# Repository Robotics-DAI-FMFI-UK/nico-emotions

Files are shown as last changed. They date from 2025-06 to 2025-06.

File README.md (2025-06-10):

# NICO: Humanoidná hlava s emóciami

Tento projekt predstavuje hlavu humanoidného robota **NICO**, ktorá dokáže zobrazovať rôzne emócie na tvári. Cieľom je vytvoriť platformu pre výskum v oblasti robotiky, umelej inteligencie a interakcie človek–robot.

## Hlavné vlastnosti

- Mechanická hlava s pohyblivými časťami tváre
- Sledovanie bodu v priestore pomocou očí
- Zobrazovanie základných emócií (radosť, smútok, strach, hnev, prekvapenie, zenchutenie,)
- Ovládanie pomocou jazykov *Python* a *C++*

## Delenie repozitára
1. 3D objects *(všetky vytlačiteľné súčasti robota vo formáte .STL)*
2. Microcontroller *(kódy riadiacej jednotky Raspberry Pi Pico 2)*
3. Python scripts *(vytvorené ovládače, ich využitie a generátor emócií)*

---

Radi privítame vaše nápady, opravy a vylepšenia.

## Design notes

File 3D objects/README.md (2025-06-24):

# Vymodelované objekty

Tento priečinok obsahuje nami vymodelované objekty novej humanoidnej hlavy a ich mechanizmov a zároveň upravený mechanizmus očí od autora [Rolf Jethon](https://bechele.de/?page_id=70).

V priečinkoch sa nachádza:
- Head - vymodelovaná hlava vo verzii .stl a zároveň aj ako objekt pre Fusion 360 sculpting ako štvorcová sieť
- Holder - držiak súčiastok, kamery a vonkajšej masky hlavy
- Eyes - použité súčiastky mechanizmu očí už s premodelovanými časťami

Ako zdroj sme použili modely pôvodnej hlavy od [SeedRobotics](https://github.com/seedrobotics/NICO-cad/tree/master).

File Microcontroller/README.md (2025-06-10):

# Program riadiacej jednotky

Tento kód bol navrhnutý pre použitie mikrokontroléra Raspberry Pi Pico 2. Program sme vyvíjali v prostedí Arduino IDE s rozšírením board manager [Arduino-Pico](https://github.com/earlephilhower/arduino-pico/). 

## Inštalácia rozšírenia
1. Treba otvoriť File -> Preferences
2. Do "Additional boards manager URLs" treba pridať:
https://github.com/earlephilhower/arduino-pico/releases/download/global/package_rp2040_index.json
3. V paneli "Boards manager" stačí vyhľadať "Raspberry Pi Pico"
4. Install

Pri inštalácií na windows je potrebné si dať pozor na pomenovanie účtu, pretože rozšírenie nedokáže korektne rozlišovať diakritiku v mene.

## Vlastné definovanie emócií

Predom sme definovali iba základné emócie. Ak má užívateľ vlastné preferencie, je potrebné zájsť do súboru **Emotions.cpp** a **Emotions.h**. Pri definovní novej emócie sú potrebné nasledovné kroky:

1. V **Emotions.cpp** vytvoríme nové pole pomenované podľa emócie a definujeme jednotlivé kroky emócie - {načasovanie, natočenia motorčekov}
2. V tom istom súbore pridáme do funkcie void Emotions::initialize() nové definície emócie:
- emotionMap[emotionCount].name = "NOVÁ EMÓCIA";
- emotionMap[emotionCount].data = nova_emocia;
- emotionMap[emotionCount++].steps = nova_emocia_steps;
3. Do súboru **Emotions.h** zapíšeme novú premennú - *extern int nova_emocia[][nova_emocia_steps]*;
4. Zvýšime počítadlo o +1 - *#define EMOTIONS_COUNT i+1*
5. Upravený kód nahráme do mikrokontroléra

Tento postup je zdĺhavý, preto ak nastane ďalšie rozširovanie práce, pridávanie vlastných emócií sa zlepší.

## Potrebné knižnice
- Arduino
- OneWire
- DallasTemperature

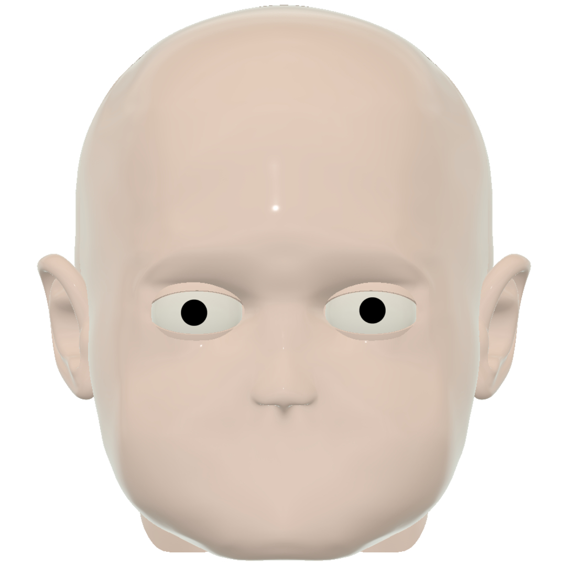
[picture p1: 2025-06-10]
Python scripts/position_generator/faces/normal.jpg

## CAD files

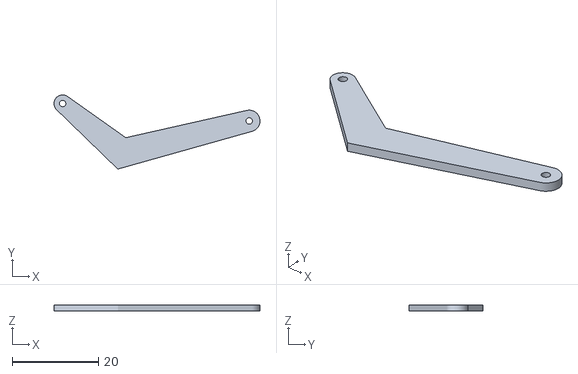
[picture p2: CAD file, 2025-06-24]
3D objects/Eyes/servo-eyeball-hinge-lever.stl
47.7 x 17.2 x 1.50

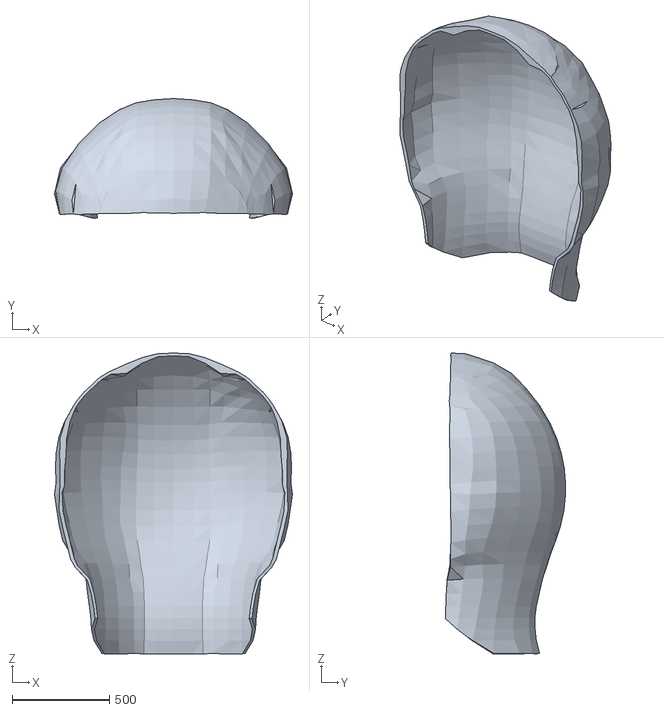
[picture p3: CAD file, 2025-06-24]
3D objects/Head/back.obj
1222.0 x 615.7 x 1545.3

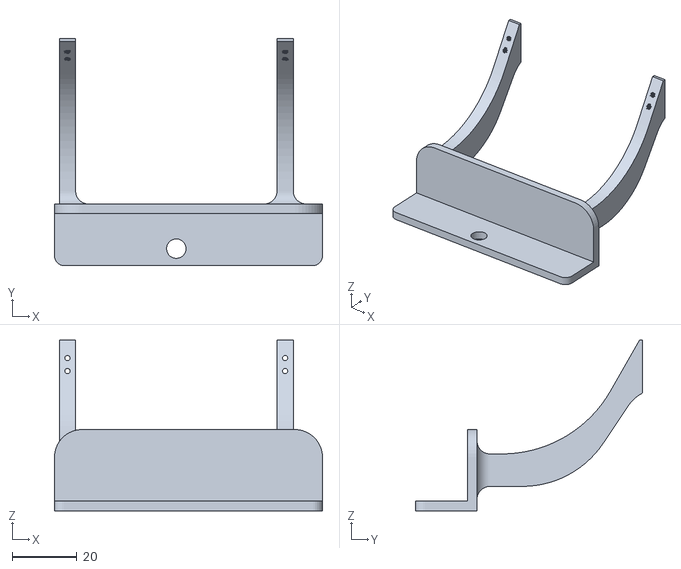
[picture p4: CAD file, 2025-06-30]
3D objects/Holder/camera_holder.stl
82.5 x 70.0 x 52.5

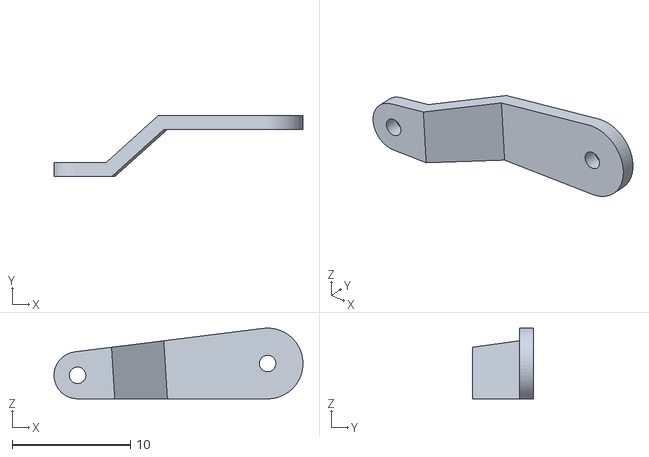
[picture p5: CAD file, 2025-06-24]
3D objects/Eyes/slider-servo-lever.stl
21.1 x 5.20 x 6.00

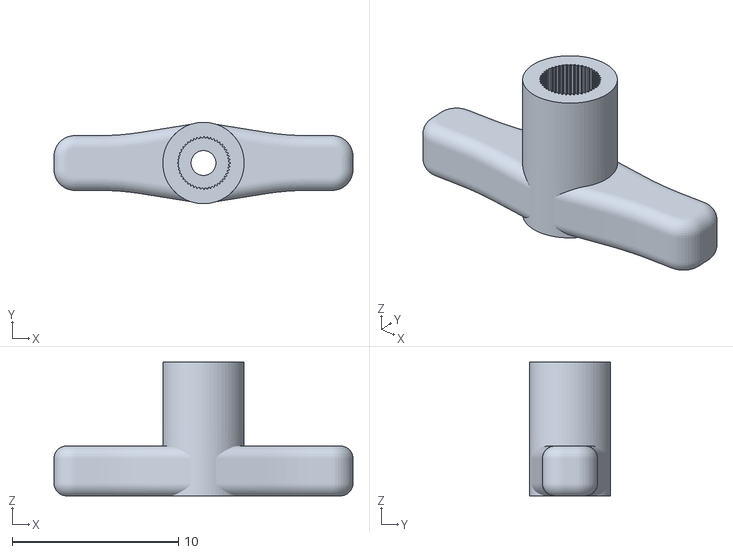
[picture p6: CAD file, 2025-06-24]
3D objects/Head/mouth_upper.stl
18.0 x 4.90 x 8.05

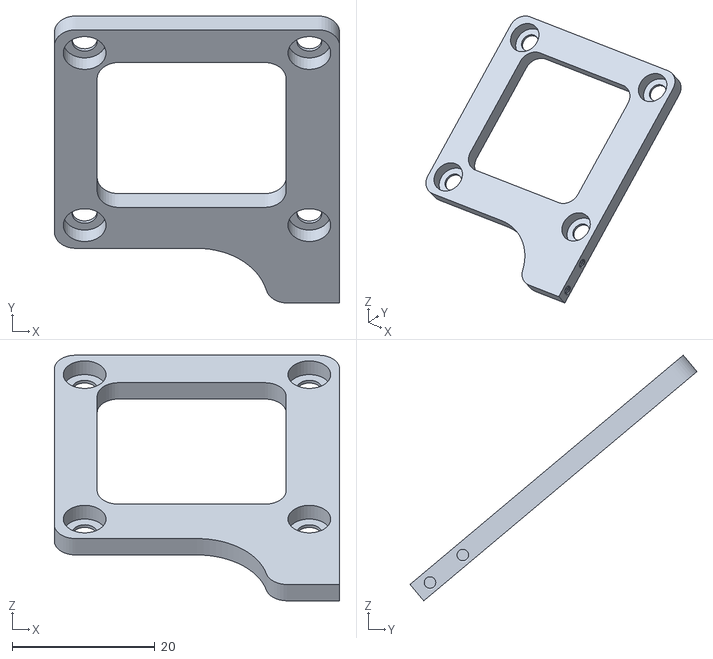
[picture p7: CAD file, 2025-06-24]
3D objects/Holder/vent_L.stl
40.0 x 40.2 x 34.4

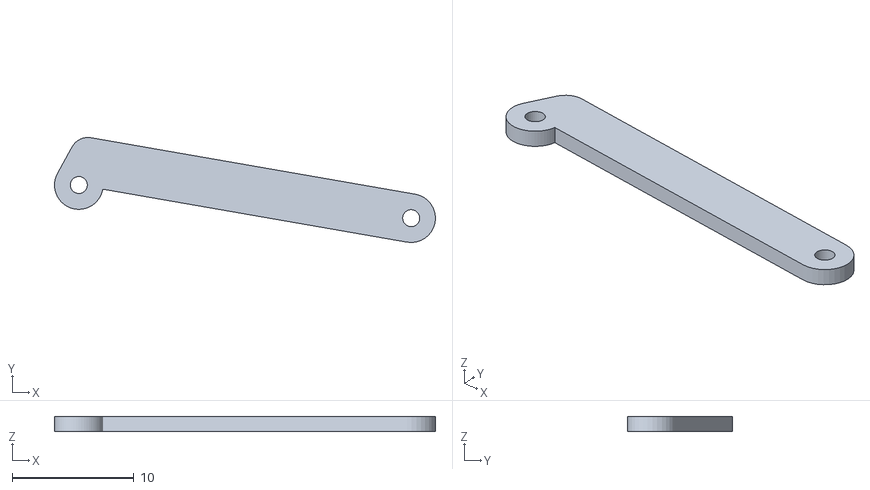
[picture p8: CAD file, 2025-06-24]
3D objects/Eyes/slider-lid-lever.stl
31.3 x 8.63 x 1.20

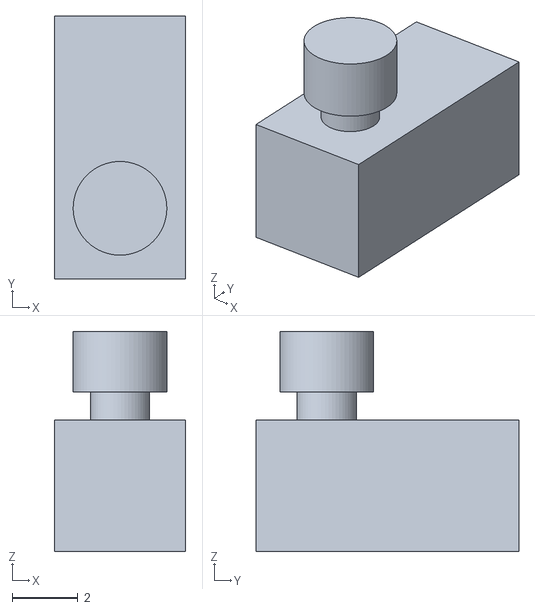
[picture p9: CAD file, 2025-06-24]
3D objects/Head/outer_connector.stl
4.00 x 8.00 x 6.70

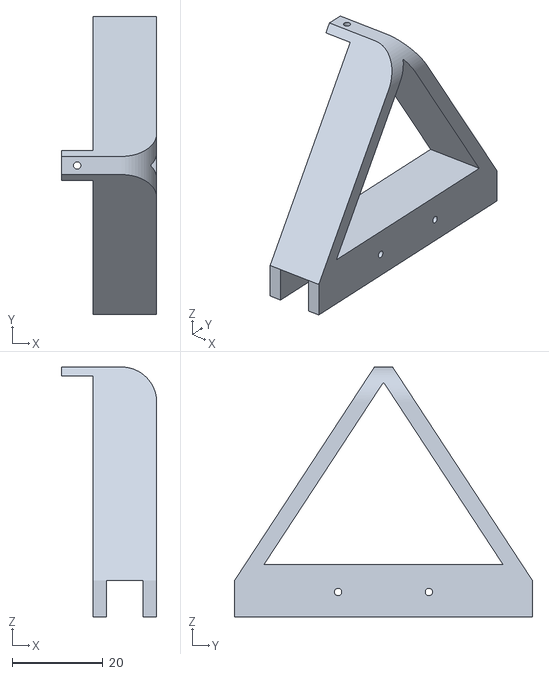
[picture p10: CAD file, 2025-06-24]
3D objects/Holder/extend_Up.stl
21.0 x 65.6 x 55.0

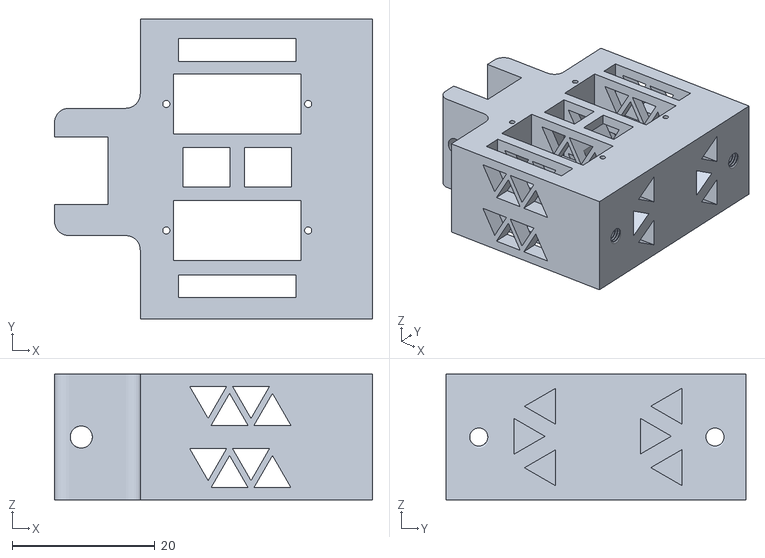
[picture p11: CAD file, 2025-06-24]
3D objects/Eyes/servoframe-lid+up-v3.stl
44.5 x 42.0 x 17.6

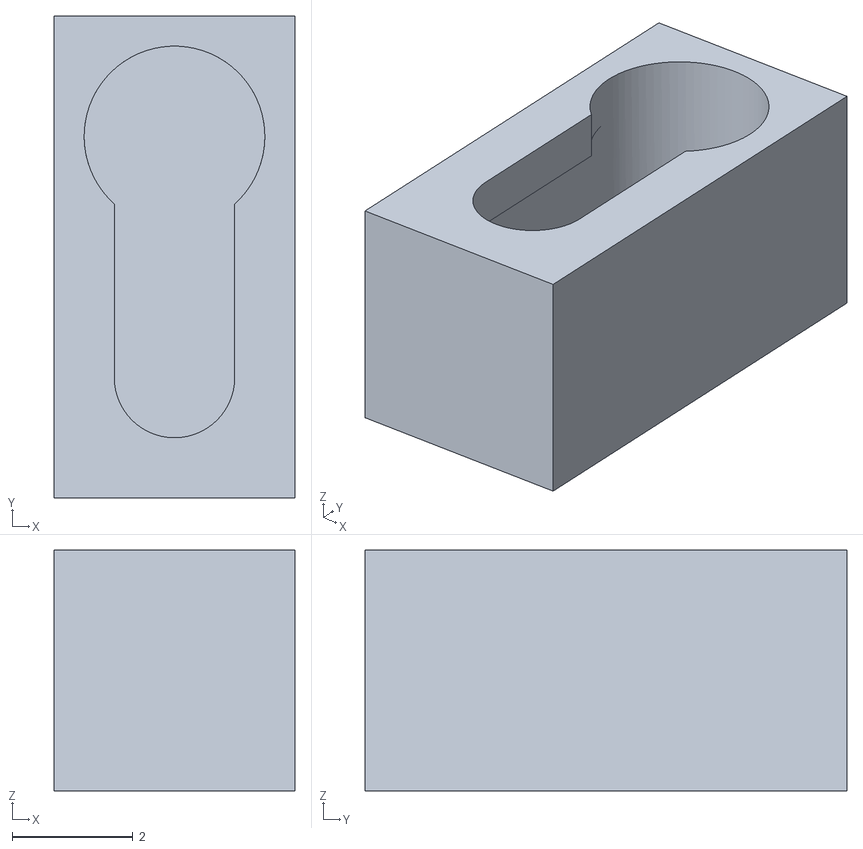
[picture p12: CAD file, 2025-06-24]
3D objects/Head/inner_connector.stl
4.00 x 8.00 x 4.00

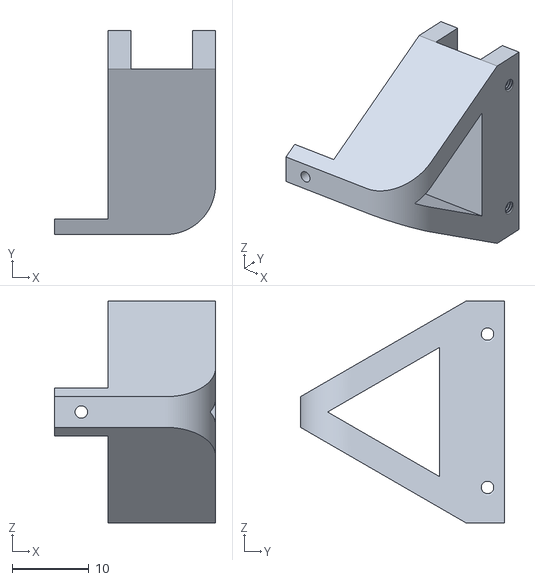
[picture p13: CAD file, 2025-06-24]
3D objects/Holder/extend_L.stl
21.0 x 26.6 x 28.9

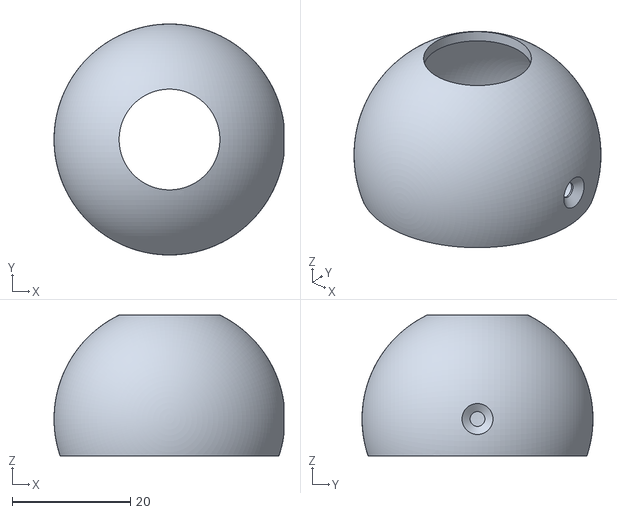
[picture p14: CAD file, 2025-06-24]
3D objects/Eyes/eyeball_for_iris.stl
38.8 x 39.0 x 23.8

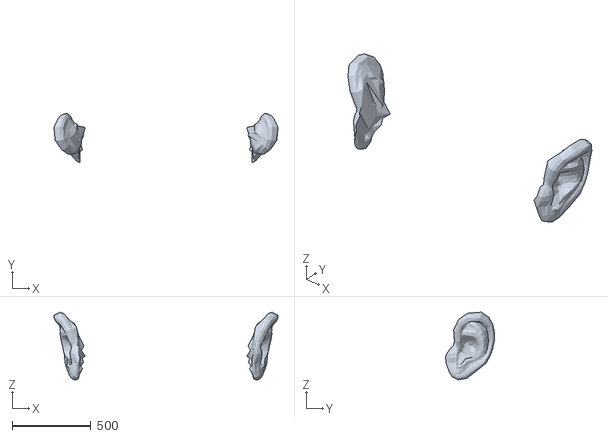
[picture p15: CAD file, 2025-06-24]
3D objects/Head/ear.obj
1419.9 x 311.5 x 429.2

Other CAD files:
3D objects/Holder/vent_R.stl
3D objects/Eyes/eyeball-hinge-v3.stl
3D objects/Head/front.obj
3D objects/Holder/extend_R.stl
3D objects/Eyes/hingeframe.stl
3D objects/Eyes/iris2.stl
3D objects/Eyes/lid-low.stl
3D objects/Eyes/lid-slider.stl
3D objects/Eyes/lid-up.stl
3D objects/Head/eyebrow.stl
3D objects/Head/mouth_lower.stl

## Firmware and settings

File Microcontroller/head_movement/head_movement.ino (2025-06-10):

#include "head_movement.h"

Mosfet leftEyeMosfet(7);
Mosfet rightEyeMosfet(6);
Mosfet mouthMosfet(18);
Mosfet ventilators(17);
Mosfet* mosfetArray[] = {&leftEyeMosfet, &rightEyeMosfet, &mouthMosfet, &ventilators};

SafetyMechanism safetyMechanism(14, A0, 16, mosfetArray);
Eye rightEye(&rightEyeMosfet, 3, 4, 5, 'R');
Eye leftEye(&leftEyeMosfet, 19, 20, 21, 'L');
EyeBrows eyebrows(&leftEyeMosfet, &rightEyeMosfet, 22, 2);
Mouth mouth(&mouthMosfet, 10, 11, 12, 13);

bool isEmotionActive = false;
String activeEmotion = "";
int emotionStep = 0;
bool systemInDanger = false;

int currentAnglePositions[12] = {
  0, 0, 0, 0, 0, 0, 0, 0, 0, 0, 0, 0
};

void setup() {
  Serial.begin(115200);  
  Emotions::initialize();
  safetyMechanism.init();

  command_turn_on("ALL");
  leftEye.init();
  rightEye.init();
  eyebrows.init();
  mouth.init();
  command_turn_off("ALL");
}

void extract_eye_parameters(const char* input, int* parameters) {
  sscanf(input, "%d,%d,%d/%d,%d,%d", 
         &parameters[0], &parameters[1], &parameters[2], 
         &parameters[3], &parameters[4], &parameters[5]);
}

void command_eyes(String input) {
  // input in format h,v,l/h,v,l

  int parameters[6];
  extract_eye_parameters(input.c_str(), parameters);

  int leftH = parameters[0];
  int leftV = parameters[1];
  int leftL = parameters[2];
  int rightH = parameters[3];
  int rightV = parameters[4];
  int rightL = parameters[5];

  leftEye.look_at(leftH, leftV);
  rightEye.look_at(rightH, rightV);

  leftEye.set_lid(leftL);
  rightEye.set_lid(rightL);
}

void extract_eyebrow_parameters(const char* input, int* parameters) {
  sscanf(input, "%d/%d", &parameters[0], &parameters[1]);
}

void command_eyebrows(String input) {
  // in format L/R

  int parameters[2];
  extract_eyebrow_parameters(input.c_str(), parameters);
  int left = parameters[0];
  int right = parameters[1]; 

  eyebrows.rotate(left, right);
}

void extract_mouth_parameters(const char* input, int* parameters) {
  sscanf(input, "%d,%d/%d,%d", &parameters[0], &parameters[1], &parameters[2], &parameters[3]);
}

void command_mouth(String input) {
  // in format UL,LL/UR,LR
  // UL - upper left, LL - lower left, UR - upper right, LR - lower right

  int parameters[4];
  extract_mouth_parameters(input.c_str(), parameters);
  int upperLeft = parameters[0];
  int lowerLeft = parameters[1];
  int upperRight = parameters[2]; 
  int lowerRight = parameters[3];

  mouth.rotate(upperLeft, lowerLeft, upperRight, lowerRight);
}

void command_face(String input) {
  // in format eyebrowL/eyebrowR:eyeL_horizontal,eyeL_vertical,eyeL_lid/eyeR_horizontal,eyeR_vertical,eyeR_lid:mouth_upperLeft,mouth_lowerLeft/mouth_upperRight,mouth_lowerRight

  int split1 = input.indexOf(':');
  int split2 = input.indexOf(':', split1 + 1);

  String eyebrowsInput = input.substring(0, split1);
  String eyesInput = input.substring(split1 + 1, split2);
  String mouthInput = input.substring(split2 + 1);

  command_eyebrows(eyebrowsInput);
  command_eyes(eyesInput);
  command_mouth(mouthInput);
}

void command_turn_on(String target) {
  if (target == "EYES") {
    leftEye.turn_on();
    rightEye.turn_on();

  } else if (target == "EYEBROWS") {
    eyebrows.turn_on();

  } else if (target == "MOUTH") {
    mouth.turn_on();

  } else if (target == "ALL") {
    leftEye.turn_on();
    rightEye.turn_on();
    eyebrows.turn_on();
    mouth.turn_on();

  } else if (target == "VENTS") {
    ventilators.turn_on();

  } else {
    Serial.println("Invalid TURN_ON target!");
  }
}

void command_turn_off(String target) {
  if (target == "EYES") {
    leftEye.turn_off();
    rightEye.turn_off();

  } else if (target == "EYEBROWS") {
    eyebrows.turn_off();

  } else if (target == "MOUTH") {
    mouth.turn_off();

  } else if (target == "ALL") {
    leftEye.turn_off();
    rightEye.turn_off();
    eyebrows.turn_off();
    mouth.turn_off();

  } else if (target == "VENTS") {
    ventilators.turn_off();

  } else {
    Serial.println("Invalid TURN_OFF target!");
  }
}

void start_emotion(String emotion) {
  isEmotionActive = true;
  activeEmotion = emotion;
  execute_emotion(emotion);
}

void execute_emotion(String emotion) {

  int (*emotionArray)[13] = Emotions::get_emotion(emotion);
  if (emotionArray == nullptr) {
    Serial.println("Emotion not found!");
    return;
  }

  int steps = Emotions::get_steps(emotion);

  if (steps <= emotionStep) {
    stop_emotion();
    return;
  }

  int* currentEmotion = emotionArray[emotionStep];
  double currentSteps[12] = {};

  for (int i = 0; i < 12; i++) {
    currentSteps[i] = currentAnglePositions[i];
  }

  double angleSteps[12] = {};

  for (int i = 0; i < 12; i++) {
    angleSteps[i] = (currentEmotion[i+1] - currentAnglePositions[i]) / 50.0;
  }
  
  int timeDelay = currentEmotion[0];
  float tStep = (timeDelay / 50.0)*1000;

  for (int t = 0; t < 50; t++) {
    eyebrows.rotate(int(currentSteps[0]+0.5), int(currentSteps[1]+0.5));
    leftEye.look_at(int(currentSteps[2]+0.5), int(currentSteps[3]+0.5));
    leftEye.set_lid(int(currentSteps[4]+0.5));
    rightEye.look_at(int(currentSteps[5]+0.5), int(currentSteps[6]+0.5));
    rightEye.set_lid(int(currentSteps[7]+0.5));
    mouth.rotate(int(currentSteps[8]+0.5), int(currentSteps[9]+0.5), int(currentSteps[10]+0.5), int(currentSteps[11]+0.5));

    for (int i = 0; i < 12; i++) {
      currentSteps[i] += angleSteps[i];
    }
    delayMicroseconds(uint32_t(tStep + 0.5));
  }
  emotionStep++;
}

void stop_emotion() {
  isEmotionActive = false;
  activeEmotion = "";
  emotionStep = 0;
}

void blink_randomly() {
  int leftLidBefore = leftEye.get_lid_state();
  int rightLidBefore = rightEye.get_lid_state();

  if (leftLidBefore <= 10 && rightLidBefore <= 10) return;

  bool leftEyeWasOff = !leftEye.is_on();
  bool rightEyeWasOff = !rightEye.is_on();

  if (leftEyeWasOff) {
    leftEye.turn_on();
  }

  if (rightEyeWasOff) {
    rightEye.turn_on();
  }

  leftEye.set_lid(0); 
  rightEye.set_lid(0);

  delay(random(80, 140));

  leftEye.set_lid(leftLidBefore); 
  rightEye.set_lid(rightLidBefore);
  
  if (leftEyeWasOff) {
    leftEye.turn_off();
  }
  
  if (rightEyeWasOff) {
    rightEye.turn_off();
  }
}

void loop() {
  static unsigned long lastSafetyCheck = 0;
  static const unsigned long safetyCheckInterval = 30000;

  if (millis() - lastSafetyCheck >= safetyCheckInterval) {
    lastSafetyCheck = millis();
    if (safetyMechanism.is_in_danger()) {
      systemInDanger = true;
    } else {
      systemInDanger = false;
    }
  }

  if (systemInDanger) {
    return;
  }

  static unsigned long lastBlink = 0;
  static unsigned long nextBlinkInterval = random(2000, 10000);

  if (millis() - lastBlink >= nextBlinkInterval) {
    blink_randomly();
    lastBlink = millis();
    nextBlinkInterval = random(5000, 15000);
  }

  if (isEmotionActive) {
    execute_emotion(activeEmotion);
  }

  if (Serial.available()) {
    String input = Serial.readStringUntil('\n');
    input.trim();

    if (input == "STOP_EMOTION") {
      stop_emotion();
      return;
    }

    if (isEmotionActive) {
      Serial.println("Vykonáva sa emócia!");
      return;
    }

    if (input == "HELLO NICO") {
      Serial.println("HELLO FROM NICO");
      return;
    } 

    int colonIndex = input.indexOf(':');

    if (colonIndex != -1) {
      String command = input.substring(0, colonIndex);
      String value = input.substring(colonIndex + 1);
      Serial.println("Command: " + command + ", Value: " + value);

      if (command.equals("EMOTION")) {
        start_emotion(value);
      } else if (command.equals("TURN_ON")) {
        command_turn_on(value);
      } else if (command.equals("TURN_OFF")) {
        command_turn_off(value);
      } else if (command.equals("EYES")) {
        command_eyes(value);
      } else if (command.equals("EYEBROWS")) {
        command_eyebrows(value);
      } else if (command.equals("MOUTH")) {
        command_mouth(value);
      } else if (command.equals("FACE")) {
        command_face(value);
      }

    } else {
      Serial.println("Unknown command!");
    }
  }
}

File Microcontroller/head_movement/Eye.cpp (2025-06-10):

#include "Eye.h"

Eye::Eye(Mosfet* mosfetPtr, int pinH, int pinV, int pinL, char eyeId)
    : mosfet(mosfetPtr), pinHorizontal(pinH), pinVertical(pinV), pinLid(pinL), eyeId(eyeId),
      horizontalAngle(90), verticalAngle(90), lidAngle(90) { }

void Eye::init() {
    servo_horizontal.attach(pinHorizontal);
    servo_vertical.attach(pinVertical);
    servo_lid.attach(pinLid);

    turn_on();
    set_horizontal(0);
    set_vertical(0);
    set_lid(0);
    turn_off();
}

void Eye::turn_on() {
    mosfet->turn_on();
}

void Eye::turn_off() {
    mosfet->turn_off();
}

bool Eye::is_on() {
    return mosfet->is_on();
}

void Eye::set_horizontal(int value) {
    if (value < -LR_ANGLE_MAX || LR_ANGLE_MAX < value) return;
    horizontalAngle = int(map(value, -LR_ANGLE_MAX, LR_ANGLE_MAX, LEFT_SERVO_MAX, RIGHT_SERVO_MAX));
    servo_horizontal.write(horizontalAngle);
    currentAnglePositions[eyeId == 'L' ? 2 : 5] = value;
}

void Eye::set_vertical(int value) {
    if (value < -UD_ANGLE_MAX || UD_ANGLE_MAX < value) return;
    verticalAngle = int(map(value, -UD_ANGLE_MAX, UD_ANGLE_MAX, DOWN_SERVO_MIN, UP_SERVO_MAX));
    servo_vertical.write(verticalAngle);
    currentAnglePositions[eyeId == 'L' ? 3 : 6] = value;
}

void Eye::set_lid(int percent) {
    if (percent < 0 || 100 < percent) return;
    lidAngle = int(map(percent, 0, 100, LID_CLOSED_MIN, LID_OPEN_MAX));
    servo_lid.write(lidAngle);
    currentAnglePositions[eyeId == 'L' ? 4 : 7] = percent;
}

int Eye::get_lid_state() {
        return int(map(lidAngle, LID_CLOSED_MIN, LID_OPEN_MAX, 0, 100));
      }

void Eye::look_at(int horizontal, int vertical) {
    set_horizontal(horizontal);
    set_vertical(vertical);
}

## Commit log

2025-06-09 Pridané súbory projektu
    [a_configuration.txt, b_configuration.txt, c_configuration.txt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]
2025-06-30 Zmena pozície kamery
    [camera_holder.stl]
